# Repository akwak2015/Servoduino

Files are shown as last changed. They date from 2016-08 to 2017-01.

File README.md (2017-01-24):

# Servoduino
Mit einem Wemos Microcontroller und einem Servo Wandtablets mit Magnetsensor an und ausschalten. 

Zuerst einmal Danke an alle, die ihre Informationen zur Arduino Programmierung mit anderen teilen. ICh nutze in diesem Projekt Bibliotheken, die über den Manager downloadbar sind. 
Für die meisten Codeteile habe ich mich im Internet inspirieren lassen. Sollte sich jemand nicht ausreichend erwähnt finden, bitte direkt bescheid sagen, damit ich nachbessern kann.

####Was ist Servoduino?
Im Homematic Forum sind viele aktive User, die ein Tablett an die Wand hängen um ihre Hausautomation zu steuern. Dabei werden die verschiedensten Verfahren genutzt um as Tablett zur richtigen Zeit an- und auszschalten.
Desweitern hat jeder User seine eigene Ladestrategie um den Tablettakku zu Schonen.
Servoduino soll viele dieser Möglichkeiten zusammenfassen und kombinieren und das mit einem überschaubaren Hardwareaufwand.

####Ist Servoduino einsatzfähig
Teilweise ist es schon einsatzfähig.
#####Was läuft:
	-	Servo an/aus per Taster, Schalter und HTTP/UDP
	-	Relais an/aus per HTTP/UDP
	-	Rückmeldung an die Homematic CCU
	-	Rückmeldung an Loxone
	-	Option Schalter wie Taster (mit eigenem Timer)
	-	Option Taster mit eigenem Timer
	-	Analoger Eingang

#####Was läuft nicht:

####Welche Hausautomationssysteme werden unterstützt?
Aktuell werden unterstützt:
	-	Homematic
	-	Loxone
	
####Welche Protokolle werden zur Steuerung genutzt?
	-	HTTP
	- 	UDP
	
####Was wird benötigt?
Auf jeden Fall einen Wemos D1 Mini. (http://www.wemos.cc/Products/d1_mini.html)
Optional:
	-	Servo mit Magnet 
	-	Relay oder Relayshield (http://www.wemos.cc/Products/relay_shield_v2.html)
	-	Max. 2 Taster
	-	Max. 2 Schalter
	-	Analoger Ausgang bis 3V (z.B. Bewegungsmelder)

#####Wo wird die Hardware angeschlossen?
Die Pin angaben sind für den Wemos D1 Mini 
#####Pinbelegung:
| Hardware | Pin |
| --- | --- |
| Servo Motor | D4 |
| Taster | D5 und/oder D6 |
| Schalter | D7 			 |
| Relais | D1 |
| Analog Eingang | A0 |
 
####Welche Befehle werden verstanden?
#####HTTP:
| URL | Funktion |
| --- | --- |
| http://ip | Einfache Übersichts Seite |
| http://ip/setup | Konfiguration |
| http://ip/an | stellt den Servomotor in Position an  |
| http://ip/an?timer=Sekunden | stellt den Servomotor in Position an für die angegebene Zeitspanne  |
| http://ip/aus | stellt den Servomotor in Position aus |
| http://ip/ran | Relais an |
| http://ip/ran?timer=Sekunden  | Relais für Sekunden an |
| http://ip/raus | Relais aus |
| | |
| http://ip/status | Status des Servomotor |
| | |
| http://ip/resetwifi | WIFI Einstellungen zurücksetzen |
| http://ip/resetconfig | Einstellungen löschen |
| http://ip/werkseinstellungen  | Einstellungen und WIFI löschen |
| http://ip/restart | Wemos neu starten |

#####UDP:
| Befehl | Funktion |
| --- | --- |
| an | Servo auf an |
| aus | Servo auf aus |
| ran | Relais an |
| raus | Relais aus |
| status | liefert 1 oder 0 zurück für Position des Servo |
| rstatus | liefert 1 oder 0 zurück für Position des Relais |
 
######Warum sind die HTML Befehle so "komisch"
Viele von Euch würden jetzt warscheinlich Befehle im Format HTTP://IP/SERVO?POS=1 oder ähnlich erwarten. 
Grund dafür ist die Homematic Benutzeroberfläche. Da gibt es bei der Eingabe von Sonderzeichen für URLs leicht Probleme. Die o.a. Befehle lassen sich ohne Tricks eingeben.

#### Wie binde ich die Homematic ein?
Dafür wird uf der CCU das Addon CUxD benötigt (http://homematic-forum.de/forum/viewtopic.php?f=37&t=15298)
Ein Gerät (28) System als Schalter anlegen.  
  
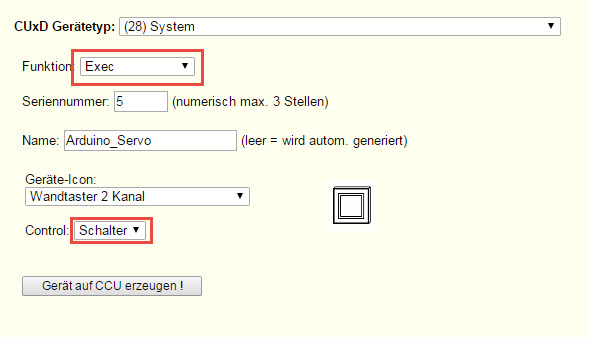
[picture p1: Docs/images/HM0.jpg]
  
  
Mit 2 Kanälen für Servo und Relais.  
In Param1: /usr/local/addons/cuxd/curl -s -m 5  
in Param2: http://ip.des.wemos.eintragen  
  
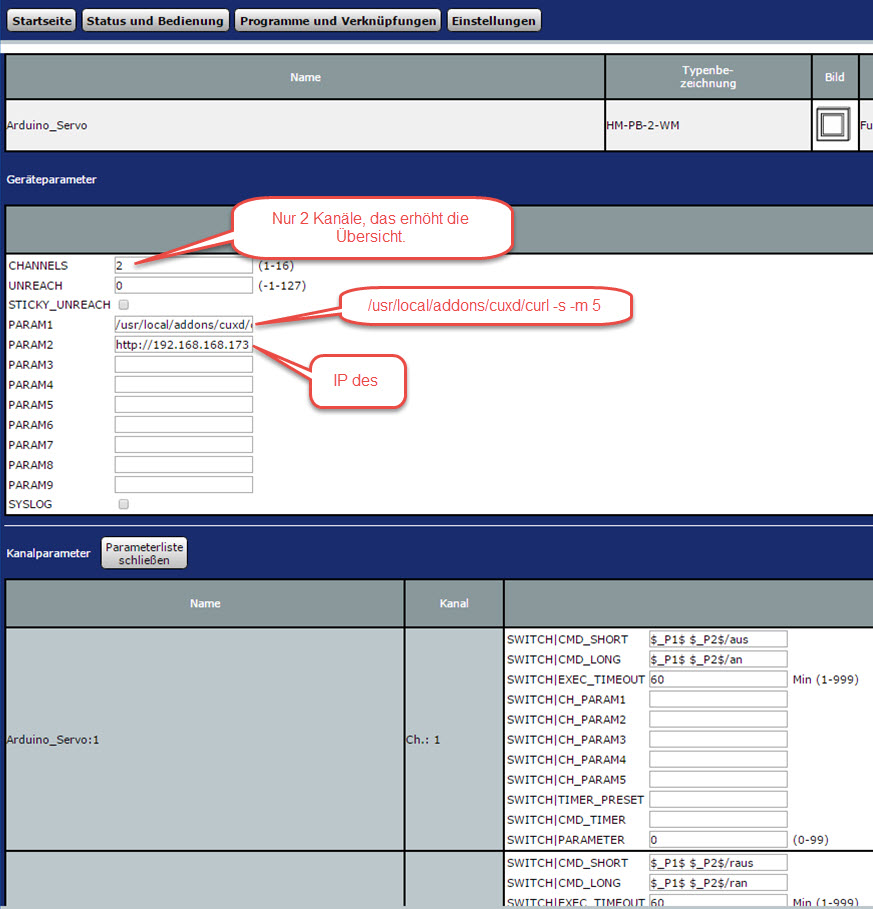
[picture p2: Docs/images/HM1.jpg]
  
  
Die Seriennummern beider Kanäle notieren  
  
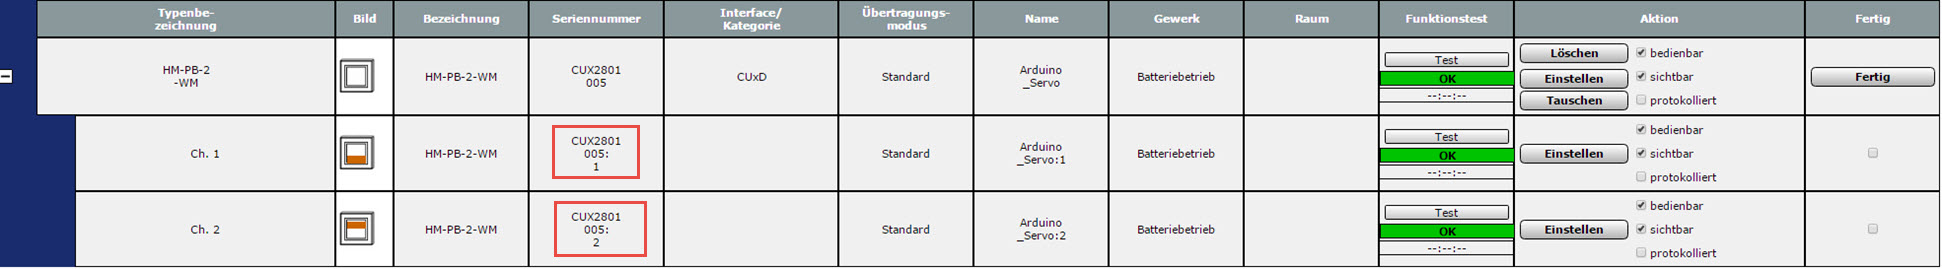
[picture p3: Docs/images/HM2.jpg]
  
  
Die IP der Homematic und die Seriennummern der beiden Kanäle im Setup auf dem Wemos eintragen
  
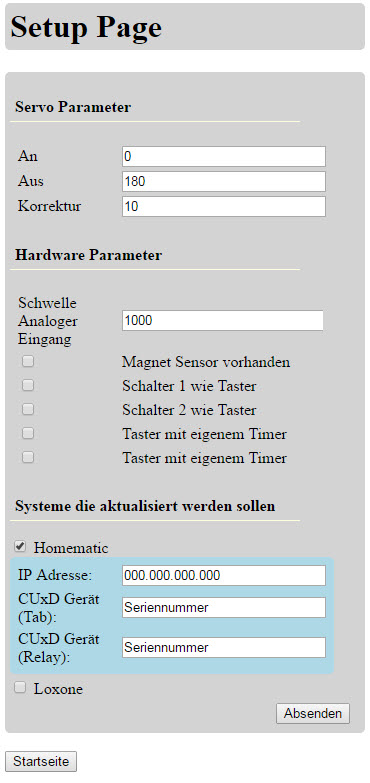
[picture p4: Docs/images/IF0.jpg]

  
####Wie binde ich Loxone ein?
Die Anwendung sendet an die angegebene IP Adresse auf dem angegebenen Port folgende Status:  
Für Jede Statusänderung des Servos oder Relais (0 für aus, 1 für an):  
	TAB1|0  
	RELAY1|0   
Für jede Taste/Schalter in eckigen Klammern [0 = Schalter 1, 1 = Schalter 2] gefolgt von 0 für aus, 1 für an:  
	Schalter[0]0|1  
	Taster[0|1]0|1  
	Web0|1  
	RWeb0|1

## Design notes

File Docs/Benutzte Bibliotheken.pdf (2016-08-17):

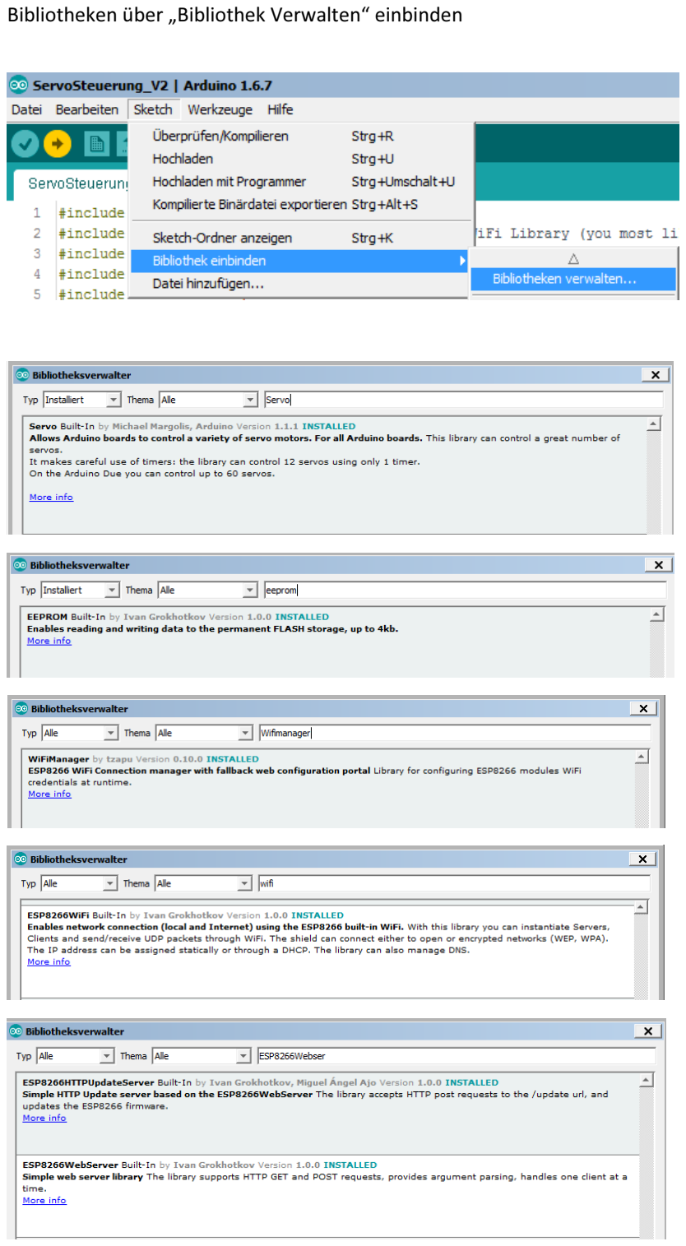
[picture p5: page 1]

Bibliotheken über „Bibliothek Verwalten“ einbinden

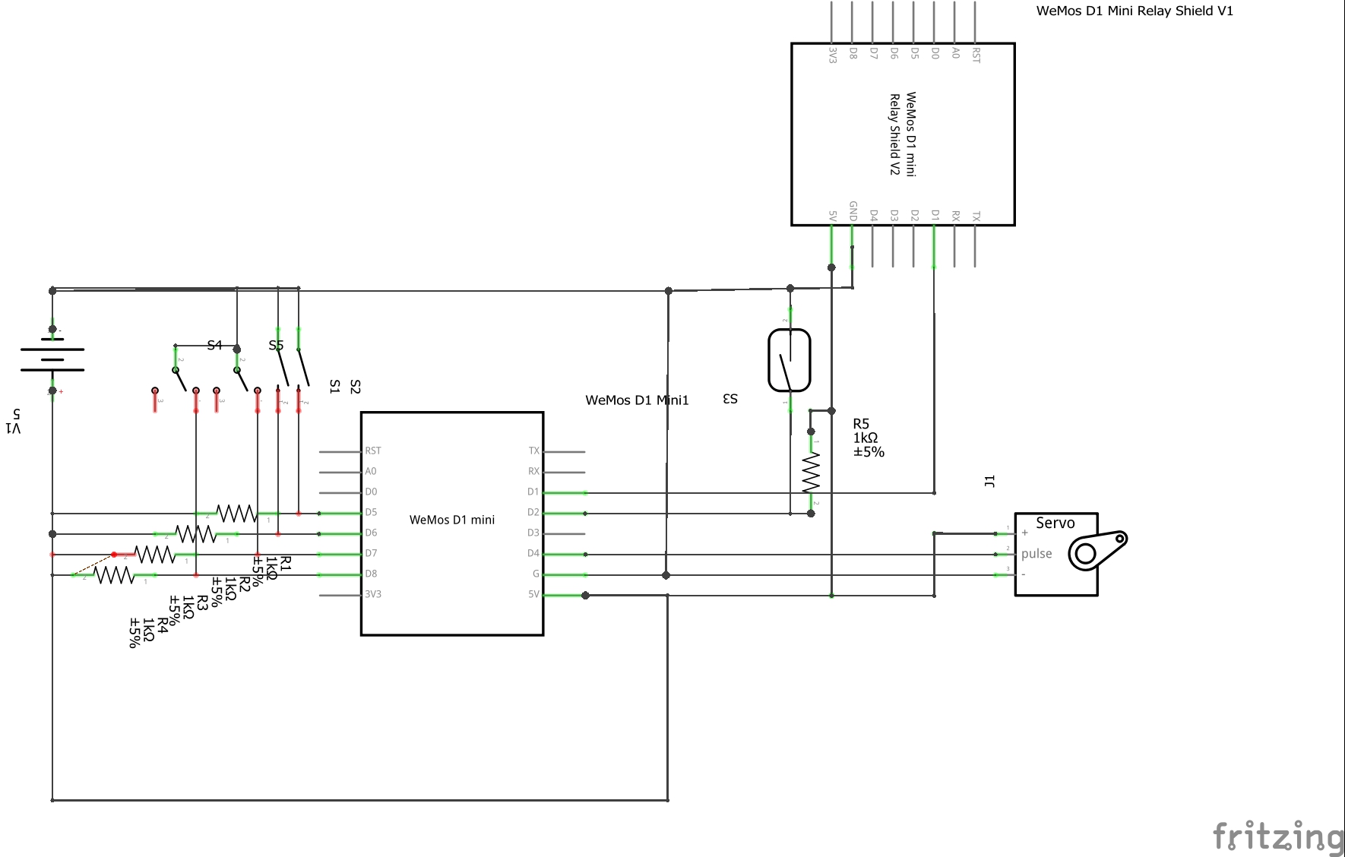
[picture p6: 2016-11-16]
Docs/Servo_Schaltplan.jpg

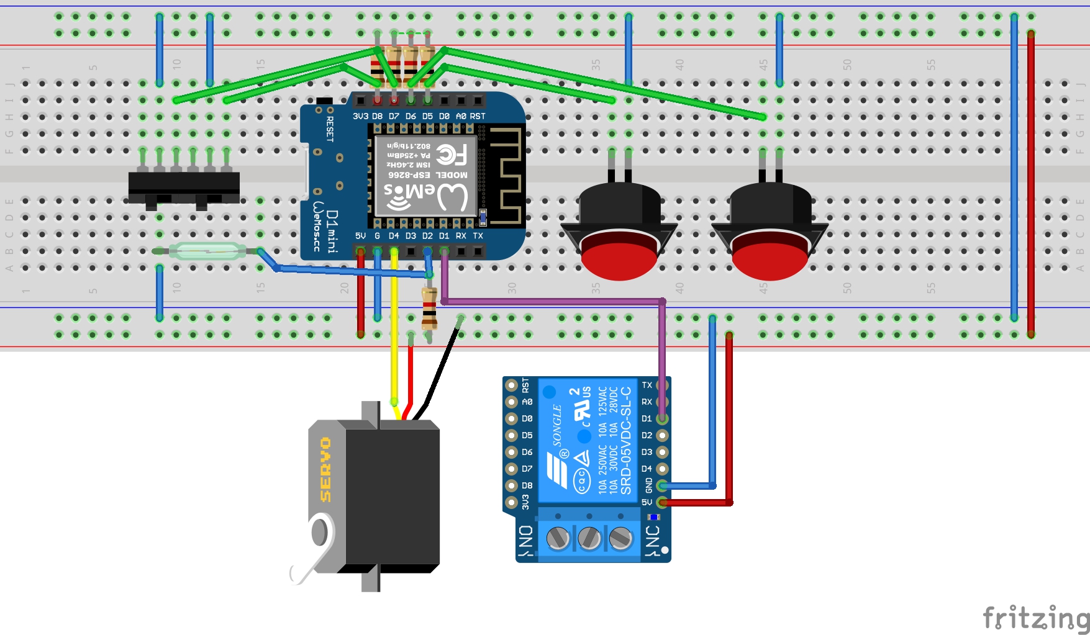
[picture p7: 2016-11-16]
Docs/Servo_Steckplatine.jpg

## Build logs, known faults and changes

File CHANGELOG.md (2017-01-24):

#Changelog:
a - added  
c - changed  
f - fixed  

##Version 0.9
c - Eingang für Reed Relais wird nicht mehr abgefragt
c - Der zweite Schaltereingang ist weggefallen
f - Analoger Input entprellt

##Version 0.8
c - Webui grafisch aufgehübscht  

##Version 0.7 
a - Timer für Relais hinzugefügt  
c - Aufgeteilt auf mehrere Dateien

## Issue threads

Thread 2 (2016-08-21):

Fehlerhafte Rückmeldung bei Schaltern

akwak2015, 2016-08-21:
Bei den Schaltern kommt immer der Gleiche Befehl im Loxone UDP Monitor an. Taster[1] und danach nichts mehr.

akwak2015, 2016-08-22:
Konvertierung String nach Char greift in einigen Fällen zu kurz. Dabei wird das letzte Zeichen verschluckt.
Workaround: Beim Konvertieren mehr Zeichen angeben als notwendig. Nicht schön, geht aber.

Closed 2016-08-26.

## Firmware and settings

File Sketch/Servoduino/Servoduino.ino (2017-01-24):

#include <ESP8266WiFi.h>          //ESP8266 Core WiFi Library (you most likely already have this in your sketch)
#include <DNSServer.h>            //Local DNS Server used for redirecting all requests to the configuration portal
#include <ESP8266WebServer.h>
#include <ESP8266HTTPClient.h> 
#include <ESP8266HTTPUpdateServer.h>
#include <WiFiManager.h>
#include <Servo.h>
#include <WiFiUdp.h>
#include <EEPROM.h>

#define iSwitchPinCount 1
#define iPushButtonPinCount 2

struct oconfig {
  int bValidConfig1;
  int bValidConfig2;
  int iConfigVersion;
  int iAn;
  int iAus;
  int iKorrektur;
  int bSwitchAsPushButton[iSwitchPinCount];
  int iSwitchTimer[iSwitchPinCount];
  int bPushButtonTimer[iPushButtonPinCount];
  int iPushButtonTimer[iPushButtonPinCount];
  int bMagnetsensor;
  int iAnalogSchwelle;
  int bHomematic;
  char sHomematicIP[16];
  char sHomematicGeraet[20];
  char sHomematicGeraetRelay[20];
  int bLoxone;
  char sLoxoneIP[16];
  char sLoxonePort[20];  
  int bIP;
  char sIP[16];
  char sSubNet[16];
  char sGateway[16]; 
  int bExpLogic;  // Schaltlogic der eingänge (switch gegen +5V oder GND) (0 fuer gegen GND)
  int iAnalogTimer;
};
typedef struct oconfig oConfig;


// *******************************************************************
// ******* Globale Variablen *****************************************
// *******************************************************************

//Version
//$Revision: 21 $
String sVersionDatum = "2017-01-20";
String sVersion = "0.9";

oConfig myConfig = {1234, 4321, 4, 0, 180, 10, {0}, {60}, {0, 0}, {120, 120}, 0 , 1000, 0, "000.000.000.000", "Seriennummer","Seriennummer", 0, "000.000.000.000", "7000" , 0, "000.000.000.000", "000.000.000.000", "000.000.000.000", 0, 120};

//Pin Definitionen
int iServoPin = 2; //WeMos mini D4
int iPushButtonPin[] = {14, 12}  ; //WeMos mini D5 und D6 (Groesse des Arrays in iPushButtonPinCount definiert (weiter oben))
int iSwitchPin[] = {13}; //WeMos mini D7 (Groesse des Arrays in iSwitchPinCount definiert (weiter oben))
int iRelayPin = 5; //Wemos mini D1 -> RelayBoard
int iMagnetsensorPin = 4; //Wemos mini D2 - MagnetSensor (Wird aktuell nicht mehr benutzt!)
// Analog Pin auf Wemos A0 => int sensorValue = analogRead(A0); 

// Aktueller Servo Status
int iServoPosAkt = -1;
int iTimerOffTime = 0;
// OTA
const char* update_path = "/firmware";
const char* update_username = "admin";
const char* update_password = "admin";

int iUeber = 0; //notwendiger "negatiever" Korrekturfaktor fue den Bereich ueber 180-iKorrektur.

int iPushButtonLastState[] = { 0, 0 };
unsigned long tPushButtonLast[2]; //letzter Tastendruck
int iSwitchLastState[] = { 0, 0 };
unsigned long tSwitchLast[2]; //letzte Schalterbetätigung

int iAnalogLastState = 0;
int iAnaloglastMillis = millis();

unsigned long iTimerMillis = millis();
bool bTimerAktiv = false;
unsigned long iRelayTimerMillis = millis();
bool bRelayTimerAktiv = false;

unsigned int localPort = 2390;      // local port to listen on
char packetBuffer[255]; //buffer to hold incoming packet
char  ReplyBuffer[] = "acknowledged";       // a string to send back

// *******************************************************************
// ******* Libraries         *****************************************
// *******************************************************************
WiFiManager wifiManager;
ESP8266WebServer server(80); // Webserver initialisieren auf Port 80
Servo myservo;
ESP8266HTTPUpdateServer httpUpdater;
WiFiUDP Udp;


// *******************************************************************
// ****** Prototypes  ************************************************
// *******************************************************************
//mycss
String cssForm();
String cssSwitch();
//myforms
void htmlresponse(String sTitel, String sInhalt);
String htmlFunction();
String htmlSwitch(String sName, int bStatus);
void wwwSetup();
void wwwRoot();
void wwwmelde_status();
void wwwmelde_FullStatus();
void htmlreloadpresite(String sTarget, String sText);
void htmlresponse0(String sText);
void wwwSwitchLogic();
//myhandler
void handlePushButton(int iPB);
void handleSwitch(int iSW);
void handleudp();
void handleAnalog();
void handleTimer();
void handleRelayTimer();
//Main
int getServo (bool bForcePinRead = false);
int getOnOffStatus(bool bForcePinRead = false);
int getStatus(bool bForcePinRead = false);
bool logichandler(int iPin = 0);

// *******************************************************************
// ******* Programm          *****************************************
// *******************************************************************

void setServo(int iPos) {
  myservo.attach(iServoPin); 
  delay(20);
  myservo.write(iPos);
  iServoPosAkt = iPos;
  delay(500);
  myservo.detach(); 
}

int getServo (bool bForcePinRead) {
  int iErg=0;
  if (bForcePinRead) {Serial.println("Force " + bForcePinRead);}
  if ((iServoPosAkt == -1) or (bForcePinRead)) {
    myservo.attach(iServoPin); 
    delay(500);
    iErg = myservo.read();
    delay(500);
    myservo.detach(); 
  }
  else {
    iErg=iServoPosAkt;
  }
  return iErg;
}

// Timer in Sekunden
void setTimerSec(int iTime) { 
  iTimerMillis = millis()+(1000 * iTime);
  bTimerAktiv = true;
  Serial.println(String(millis()) + "Timer aktiv: " + String(1000*iTime));
}

void setRelayTimerSec(int iTime) { 
  iRelayTimerMillis = millis()+(1000 * iTime);
  bRelayTimerAktiv = true;
  Serial.println("Relay Timer aktiv: " + String(1000*iTime));
}

void saveConfig() {
  Serial.println("__________ Save Config ________");
  int eeAddress = 0;
  EEPROM.begin(256);
  EEPROM.put(eeAddress, myConfig);
  delay(200);
  EEPROM.end();
}


int getKorrigiert (int iGrad) {
  int iErg = iGrad;
  iErg = iErg + myConfig.iKorrektur;
  iUeber=0;
  if (iErg > 180) { 
    iUeber=iErg-180;
    if (iUeber>myConfig.iKorrektur) iUeber=myConfig.iKorrektur;
    iErg=180;
  }
  if (iErg < 0) iErg=0;
  // Serial.println("getKorrigiert - Input: " + String(iGrad) + " Rueckgabe: "+ String(iErg));
  return iErg;
}

int getStatus(bool bForcePinRead) {
  int iErg = getServo(bForcePinRead);
  iErg=iErg - myConfig.iKorrektur;
  if (iErg > 180) iErg=180;
  if (iErg < 0) iErg=0;
  //Serial.println("getKorrigiert - ServoPos: " + String( getServo()) + " Rueckgabe: "+ String(iErg));
  return iErg+iUeber;
}

int getOnOffStatus(bool bForcePinRead) {
    int iErg=-1;
//    if (myConfig.bMagnetsensor==1) {
//      delay(500);
//      if (logichandler(iMagnetsensorPin) == HIGH) {
//        iErg=1;
//      } else {
//        iErg=0;
//      }
//  } else {    
    int iStatus = getStatus(bForcePinRead);
    if (iStatus == myConfig.iAn) iErg=1; 
    if (iStatus == myConfig.iAus) iErg=0; 
//  }
  return iErg;
}

// Rückmeldungen an Loxone

void sendUDP(String sUDP) {
    if (myConfig.bLoxone != 1) {return;}
    int iPort =  atoi(myConfig.sLoxonePort); 
    Serial.print("Anzahl Zeichen:");
    Serial.println(sizeof(sUDP)+2); //+2 um sicher alle Zeichen zu erwischen.
    char  sBuffer[sizeof(sUDP)] = "";
    sUDP.toCharArray(sBuffer,sizeof(sUDP)+2);
    Serial.print("Sende an Loxone: ");
    Serial.println(sBuffer); 
    Udp.beginPacket(myConfig.sLoxoneIP, iPort);
    Udp.write(sBuffer);
    Udp.endPacket(); 
}
void sendTabState2Loxone() {
//    if (myConfig.bLoxone != 1) {return;}
//    int iPort =  atoi(myConfig.sLoxonePort); 
//    int iStatus = getOnOffStatus();
//    char  sBuffer[6] = "";
//    String("TAB" + String(iStatus)).toCharArray(sBuffer,6);
//    Serial.print("Sende an Loxone: ");
//    Serial.println(sBuffer); 
//    Udp.beginPacket(myConfig.sLoxoneIP, iPort);
//    Udp.write(sBuffer);
//    Udp.endPacket();
    if (myConfig.bLoxone != 1) {return;}
    int iStatus = getOnOffStatus();
    sendUDP("TAB" + String(iStatus));
}
void sendRelayState2Loxone() {
    if (myConfig.bLoxone != 1) {return;}
//    int iPort  = atoi(myConfig.sLoxonePort); 
//    int iStatus = (iRelayPin);
//    char  sBuffer[8] = "";
//    String("RELAY" + String(iStatus)).toCharArray(sBuffer,8); 
//    Serial.print("Sende an Loxone: ");
//    Serial.println(sBuffer); 
//    Udp.beginPacket(myConfig.sLoxoneIP, iPort);
//    Udp.write(sBuffer);
//    Udp.endPacket();
    int iStatus = digitalRead(iRelayPin);
    sendUDP("Relay" + String(iStatus));
}

// Rückmeldungen an Homematic
void sendHTML(String sURL) {
  HTTPClient http;
  Serial.print("[HTTP] begin...\n");
  Serial.println(sURL);
  http.begin(sURL);
  int httpCode = http.GET();
  if(httpCode > 0) {
      // HTTP header has been send and Server response header has been handled
      Serial.printf("[HTTP] GET... code: %d\n", httpCode);

      // file found at server
      if(httpCode == HTTP_CODE_OK) {
          String payload = http.getString();
          Serial.println(payload);
      }
  } else {
      Serial.printf("[HTTP] GET... failed, error: %s\n", http.errorToString(httpCode).c_str());
  }

  http.end();

}

void sendTabState2HM(){
  if (myConfig.bHomematic != 1) {return;}
  String sURL ="http://";
  sURL += myConfig.sHomematicIP;
  sURL += ":8181/cuxd.exe?x=dom.GetObject(\"CUxD.";
  sURL += myConfig.sHomematicGeraet;
  sURL +=".SET_STATE\").State(";
  sURL += String(getOnOffStatus());
  sURL += ")";
  sendHTML(sURL);  
}

void sendRelayState2HM(){
  if (myConfig.bHomematic != 1) {return;}
  String sURL ="http://";
  sURL += myConfig.sHomematicIP;
  sURL += ":8181/cuxd.exe?x=dom.GetObject(\"CUxD.";
  sURL += myConfig.sHomematicGeraetRelay;
  sURL +=".SET_STATE\").State(";
  sURL +=  digitalRead(iRelayPin);
  sURL += ")";
  sendHTML(sURL);  
}

void sendTabState() {
  sendTabState2Loxone();
  sendTabState2HM();  
}

void sendRelayState() {
  sendRelayState2Loxone();
  sendRelayState2HM();
}

void sendState() {
  sendTabState();
  sendRelayState();
}


void goPos() {
  if (server.arg("pos")!="") {
//  String sStatus = server.arg("pos");
//  iStatus=sStatus.toInt();    
  int iStatus = server.arg("pos").toInt();
  if (iStatus<0) { iStatus = 0; }
  if (iStatus>360) { iStatus = 360; }
   
  setServo(getKorrigiert(iStatus));
  htmlresponse0(String(getStatus()));
  }
}

void wwwrelayan() {
  String bReload = server.arg("reload");
  String sTimer = server.arg("timer");
  int iTimer=0;
  digitalWrite(iRelayPin, HIGH);
  if (sTimer!="") {
    iTimer = sTimer.toInt();
      if (iTimer > 0) {
          setRelayTimerSec(iTimer);   
      }
  }
  else {
     bRelayTimerAktiv = false;
  } 

  if (bReload == "1") {
    Serial.println("Zur Root Seite weiterleiten");
    htmlreloadpresite("/","AN");
  }
  else {
    Serial.println("NICHT weiterleiten");
    htmlresponse0("1");
  }
    sendUDP("RWeb1");
    sendRelayState();  
}

void wwwrelayaus() {
  String bReload = server.arg("reload");
  digitalWrite(iRelayPin, LOW);
  bRelayTimerAktiv = false;
  if (bReload == "1") {
    Serial.println("Zur Root Seite weiterleiten");
    htmlreloadpresite("/","AUS");
  }
  else {
    Serial.println("NICHT weiterleiten");
    htmlresponse0("0");
  }
  sendUDP("RWeb0");
  sendRelayState(); 
}

void wwwan() {
  String bReload = server.arg("reload");
  String sTimer = server.arg("timer");
  int iTimer=0;
  Serial.println("Reload? = " + bReload);
  Serial.println("Timer? = " + sTimer);
  int iStatus=myConfig.iAn;
  setServo(getKorrigiert(iStatus));
  if (sTimer!="") {
    iTimer = sTimer.toInt();
      if (iTimer > 0) {
          setTimerSec(iTimer);   
      } 
  }
  else {
      bTimerAktiv = false;
  }

  if (bReload == "1") {
    Serial.println("Zur Root Seite weiterleiten");
    htmlreloadpresite("/","AN");
  }
  else {
    Serial.println("NICHT weiterleiten");
    htmlresponse0("1");
  }
  sendUDP("Web1");
  sendTabState();  
}

void wwwaus() {
  String bReload = server.arg("reload");
  Serial.println("Reload? = " + bReload);
  int iStatus=myConfig.iAus;
  setServo(getKorrigiert(iStatus));
  if (bReload == "1") {
    Serial.println("Zur Root Seite weiterleiten");
    htmlreloadpresite("/","AUS");
  }
  else {
    Serial.println("NICHT weiterleiten");
    htmlresponse0("0");
  }
  sendUDP("Web0");
  sendTabState();
  bTimerAktiv=false;  
}

void  wwwanwert() {
    int sensorValue = analogRead(A0);
    htmlresponse0(String(sensorValue));  
}



String htmlDisplay(int iState) {
  String sRet = "";
  if (iState == 1) {
     sRet = "style=\"display: inline-block;\"";
  }
  else {
     sRet = "style=\"display: none;\"";
  }
  return sRet;
}


void wwwSave() {
  String sAn = server.arg("an");
  String sAus = server.arg("aus");
  String sKorrektur = server.arg("korrektur");
  String sSchalterWieTaster1 = server.arg("SchalterWieTaster1");
  String sSchalterTime1 = server.arg("SchalterTime1");
  String sTasterMitTimer1 = server.arg("TasterMitTimer1");
  String sTasterTime1 = server.arg("TasterTime1");
//  String sSchalterWieTaster2 = server.arg("SchalterWieTaster2");
//  String sSchalterTime2 = server.arg("SchalterTime2");
  String sTasterMitTimer2 = server.arg("TasterMitTimer2");
  String sTasterTime2 = server.arg("TasterTime2");
  String sMagnetSchalter = server.arg("MagnetSchalter");
  String sAnalogSchwelle = server.arg("AnalogSchwelle");
    
  String sHM = server.arg("HM");
//  -----
  String sHMIP = server.arg("HMIP");
  String sHMGERAET = server.arg("HMGERAET");
  String sHMGERAETRELAY = server.arg("HMGERAETRELAY");
//  -----  
  String sLox = server.arg("Lox");
  String sLoxIP = server.arg("LoxIP");
  String sLoxPort = server.arg("LoxPort");
// IP ---
  String bIP = server.arg("FesteIP");
  String sIP = server.arg("IP");
  String sSubNet = server.arg("Sub");
  String sGateway = server.arg("GW"); 
  String bExpLogic = server.arg("Logic");
  String sAnalogTimer = server.arg("AnalogTime");

  Serial.println("Save Parameter Temporarly ------");
  Serial.println("an:                 " + sAn );
  Serial.println("aus:                " + sAus );
  Serial.println("korrektur:          " + sKorrektur );
  Serial.println("-------------------------------");
  Serial.println("SchalterWieTaster1: " + sSchalterWieTaster1 );
  Serial.println("SchalterTime1:      " + sSchalterTime1 );
  Serial.println("TasterMitTimer1:    " + sTasterMitTimer1 );
  Serial.println("TasterTime1:        " + sTasterTime1 );
  Serial.println("---");
//  Serial.println("SchalterWieTaster2: " + sSchalterWieTaster2 );
//  Serial.println("SchalterTime2:      " + sSchalterTime2 );
  Serial.println("TasterMitTimer2:    " + sTasterMitTimer2 );
  Serial.println("TasterTime2:        " + sTasterTime2 );
  Serial.println("Analog Time:        " + sAnalogTimer);
//  Serial.println("MagnetSchater:      " + sMagnetSchalter );
  Serial.println("AnalogSchwelle:     " + sAnalogSchwelle );

  Serial.println("-------------------------------");
  Serial.println("Homematic           " + sHM );
  Serial.println("Homematic IP        " + sHMIP );
  Serial.println("Homematic Geraet    " + sHMGERAET );
  Serial.println("Homematic Geraet Re " + sHMGERAETRELAY );
  Serial.println("Loxone              " + sLox );
  Serial.println("Loxone IP           " + sLoxIP );
  Serial.println("Loxone Geraet       " + sLoxPort );
  Serial.println("-------------------------------");
  Serial.println("Feste IP:           " + bIP);
  Serial.println("IP                  " + sIP);
  Serial.println("Subnet              " + sSubNet);
  Serial.println("Gateway             " + sGateway); 
  Serial.println("-------------------------------");
  Serial.println("Logic               " + String(bExpLogic));
  Serial.println("-------------------------------");
 
  if (sAn!="") {myConfig.iAn = sAn.toInt();}
  if (sAus!="") {myConfig.iAus = sAus.toInt();}
  if (sKorrektur!="") {myConfig.iKorrektur = sKorrektur.toInt();}

// -------------------- Schalter wie Taster   --------------
// Schalter 1
  if (sSchalterWieTaster1 =="on") {
      myConfig.bSwitchAsPushButton[0] = 1;
      if (sSchalterTime1!="") {
         myConfig.iSwitchTimer[0] = sSchalterTime1.toInt();
      }
  }
  else {
    myConfig.bSwitchAsPushButton[0] = 0;
  }

//Schalter 2
//  if (sSchalterWieTaster2 =="on") {
//      myConfig.bSwitchAsPushButton[1] = 1;
//      if (sSchalterTime2!="") {
//         myConfig.iSwitchTimer[1] = sSchalterTime2.toInt();
//      }
//  }
//  else {
//    myConfig.bSwitchAsPushButton[1] = 0;
//  }

// ---------------------- Taster mit Timer -------------------
//Taster 1  
  if (sTasterMitTimer1 =="on") {
       myConfig.bPushButtonTimer[0] = 1;
      if (sTasterTime1!="") {
         myConfig.iPushButtonTimer[0] = sTasterTime1.toInt();
      }
  }
  else {
     myConfig.bPushButtonTimer[0] = 0;
  }
  
// Taster 2
  if (sTasterMitTimer2 =="on") {
       myConfig.bPushButtonTimer[1] = 1;
      if (sTasterTime2!="") {
         myConfig.iPushButtonTimer[1] = sTasterTime2.toInt();
      }
  }
  else {
     myConfig.bPushButtonTimer[1] = 0;
  }

// Analog Timer
  if (sAnalogTimer!="") {
     myConfig.iAnalogTimer = sAnalogTimer.toInt();
  }

  //Quick and dirty - Magnetsensorfunktion deaktivieren
  myConfig.bMagnetsensor = 0;
//  if (sMagnetSchalter =="on") {
//          myConfig.bMagnetsensor = 1;
//      } else {
//          myConfig.bMagnetsensor = 0;
//      }

  if (sAnalogSchwelle !="") { myConfig.iAnalogSchwelle = sAnalogSchwelle.toInt();}
  
// ----- Homematic
  if (sHM =="on") { 
        myConfig.bHomematic = 1;
     } else {
        myConfig.bHomematic = 0;        
     }
   
  if (sHMIP !="") { sHMIP.toCharArray(myConfig.sHomematicIP,16);}
  if (sHMGERAET !="") { sHMGERAET.toCharArray(myConfig.sHomematicGeraet ,20);}
  if (sHMGERAETRELAY !="") { sHMGERAETRELAY.toCharArray(myConfig.sHomematicGeraetRelay ,20);}

// -----Loxone
  if (sLox =="on") { 
        myConfig.bLoxone = 1;
     } else {
        myConfig.bLoxone = 0;
     }

  if (sLoxIP !="") { sLoxIP.toCharArray(myConfig.sLoxoneIP,16) ;}
  if (sLoxPort  !="") { sLoxPort.toCharArray( myConfig.sLoxonePort ,20);}

  if (bIP =="on") { 
        myConfig.bIP = 1;
     } else {
        myConfig.bIP = 0;        
     }
   
  if (sIP != "") { sIP.toCharArray(myConfig.sIP,16);}
  if (sSubNet != "") { sSubNet.toCharArray(myConfig.sSubNet ,16);}
  if (sGateway != "") { sGateway.toCharArray(myConfig.sGateway,16);} 

  if (bExpLogic =="on") {
    myConfig.bExpLogic = 1;
    }
    else {
      myConfig.bExpLogic = 0;
    }
  saveConfig();
  delay(200);
  htmlreloadpresite("/setup","Speicher Parameter");
 
}


void printConfig() {
 Serial.println("Valid1 (1234): " + String(myConfig.bValidConfig1));
 Serial.println("Valid2 (4321): " + String(myConfig.bValidConfig2));  
 Serial.println("Config Ver.  : " + String(myConfig.iConfigVersion));
 Serial.println("An           : " + String(myConfig.iAn));
 Serial.println("Aus          : " + String(myConfig.iAus));
 Serial.println("Korrektur    : " + String(myConfig.iKorrektur));
 Serial.println("SwitchAsPush : " + String(myConfig.bSwitchAsPushButton[0]));
 Serial.println("SwitchTimer  : " + String(myConfig.iSwitchTimer[0]));
 Serial.println("PB with Timer: " + String(myConfig.bPushButtonTimer[0]));
 Serial.println("PB Timer     : " + String(myConfig.iPushButtonTimer[0]));  
// Serial.println("SwitchAsPush : " + String(myConfig.bSwitchAsPushButton[1]));
// Serial.println("SwitchTimer  : " + String(myConfig.iSwitchTimer[1]));
 Serial.println("PB with Timer: " + String(myConfig.bPushButtonTimer[1]));
 Serial.println("PB Timer     : " + String(myConfig.iPushButtonTimer[1]));
 Serial.println("Analog Timer : " + String(myConfig.iAnalogTimer)); 
 Serial.println("Homematic    : " + String(myConfig.bHomematic)); 
 Serial.println("Homatic IP   : " + String(myConfig.sHomematicIP)); 
 Serial.println("Homematic Ger: " + String(myConfig.sHomematicGeraet)); 
 Serial.println("Loxone       : " + String(myConfig.bLoxone)); 
 Serial.println("Loxone IP    : " + String(myConfig.sLoxoneIP)); 
 Serial.println("Loxone Geraet: " + String(myConfig.sLoxonePort)); 
 Serial.println("Logic Inputs : " + String(myConfig.bExpLogic)); 

}
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
void loop() {
  // put your main code here, to run repeatedly:
    server.handleClient(); // auf HTTP-Anfragen warten
    for (int i=0; i<iPushButtonPinCount ; i++) {
        handlePushButton(i);
    }    
    for (int i=0; i<iSwitchPinCount ; i++) {
        handleSwitch(i);
    }
    handleAnalog();
    handleudp();
    handleTimer();
    handleRelayTimer();
    delay(100);
}

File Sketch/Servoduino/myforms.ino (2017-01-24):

String htmlSwitch(String sName, int bStatus, String sID ="") {
  String sReturn;
  String sStatus = "";
  if (bStatus==1) {
    sStatus="checked";
  }
  sReturn = "<label class=\"switch\">";
  sReturn += "<input type=\"checkbox\" name=\""+sName+"\" "+ sStatus ;
  if (sID !="") {sReturn += " onchange = \"showhide('"+sID + "' , this.checked)\"";}
  sReturn += ">";
  sReturn += "<div class=\"slider round\"></div>";
  sReturn += "</label>";
  return(sReturn);
}

String htmlFunction() {
  String sReturn ="\n";
  sReturn += "<script type=\"text/javascript\">\n";
  sReturn += "function toggle(control){\n";
  sReturn += "    var elem = document.getElementById(control);\n";
  sReturn += "\n";
  sReturn += "    if(elem.style.display == \"none\"){\n";
  sReturn += "        elem.style.display = \"inline-block\";\n";
  sReturn += "    }else{\n";
  sReturn += "        elem.style.display = \"none\";\n";
  sReturn += "    }\n";
  sReturn += "}\n";

  sReturn += "function showhide(control, val){\n";
  sReturn += "  var elem = document.getElementById(control);\n";
  sReturn += "  if(val){\n";
  sReturn += "    elem.style.display = \"inline-block\"\n";
  sReturn += "  }else{\n";
  sReturn += "    elem.style.display = \"none\";\n";
  sReturn += "  }\n";
  sReturn += "}\n";  
  sReturn += "</script>\n";

  sReturn += "<script type=\"text/javascript\">\n";
  sReturn += "var xmlHttpObject = false;\n";
  sReturn += "// Überprüfen ob XMLHttpRequest-Klasse vorhanden und erzeugen von Objekte für IE7, Firefox, etc.\n";
  sReturn += "if (typeof XMLHttpRequest != 'undefined') \n";
  sReturn += "{\n";
  sReturn += "    xmlHttpObject = new XMLHttpRequest();\n";
  sReturn += "}\n";
  sReturn += "";
  sReturn += "// Wenn im oberen Block noch kein Objekt erzeugt, dann versuche XMLHTTP-Objekt zu erzeugen\n";
  sReturn += "// Notwendig für IE6 oder IE5\n";
  sReturn += "if (!xmlHttpObject) \n";
  sReturn += "{\n";
  sReturn += "    try \n";
  sReturn += "    {\n";
  sReturn += "        xmlHttpObject = new ActiveXObject(\"Msxml2.XMLHTTP\");\n";
  sReturn += "    }\n";
  sReturn += "    catch(e) \n";
  sReturn += "    {\n";
  sReturn += "        try \n";
  sReturn += "        {\n";
  sReturn += "            xmlHttpObject = new ActiveXObject(\"Microsoft.XMLHTTP\");\n";
  sReturn += "        }\n";
  sReturn += "        catch(e) \n";
  sReturn += "        {\n";
  sReturn += "            xmlHttpObject = null;\n";
  sReturn += "        }\n";
  sReturn += "    }\n";
  sReturn += "}</script>\n";

  sReturn += "<script type=\"text/javascript\">\n";
  sReturn += "function sndReq()\n";
  sReturn += "{\n";   
  sReturn += "xmlHttpObject.open('get', '/anwert', true);\n";
  sReturn += "xmlHttpObject.send();";
  sReturn += "  xmlHttpObject.onreadystatechange = function () {\n";
  sReturn += "    if(xmlHttpObject.readyState == 4)\n";
  sReturn += "    {\n";
  sReturn += "      document.getElementById('divAnWert').innerHTML = xmlHttpObject.responseText\n";
  sReturn += "    }\n";
  sReturn += "  }\n";
  sReturn += "  http.send(null);\n";
  sReturn += "}\n";
  sReturn += "</script>  \n";

  sReturn += "<script type=\"text/javascript\">\n";
  sReturn += "function sndReqFull()\n";
  sReturn += "{\n";   
  sReturn += "xmlHttpObject.open('get', '/fullstatus', true);\n";
  sReturn += "xmlHttpObject.send();\n";
  sReturn += "  xmlHttpObject.onreadystatechange = function () {\n";
  sReturn += "    if(xmlHttpObject.readyState == 4)\n";
  sReturn += "    {\n";
  sReturn += "      document.getElementById('divFull').innerHTML = xmlHttpObject.responseText\n";
  sReturn += "    }\n";
  sReturn += "  }\n";
//  sReturn += "  http.send(null);\n";
  sReturn += "}\n";
  sReturn += "</script>  \n";
  return sReturn;
}
void htmlresponse(String sTitel, String sInhalt) {
    String sResponse;
    Serial.println("htmlresponse begin");
    sResponse  = "<!DOCTYPE HTML PUBLIC \"-//W3C//DTD HTML 4.01//EN\" \"http://www.w3.org/TR/html4/strict.dtd\">\n";
    sResponse += "<html lang=\"de\"><head>\n";
    sResponse += "<meta http-equiv=\"content-type\" content=\"text/html; charset=utf-8\">\n";
    sResponse += "<Style type=\"text/css\">\n";
    sResponse += cssSwitch();
    sResponse += cssForm();
    sResponse += "</style>\n";
    sResponse += htmlFunction();
    sResponse += "<title>\n";
    sResponse += sTitel;
    sResponse += "</title></head><body>\n";
    sResponse += sInhalt;
    sResponse += "</body></html>\n";
    Serial.println("htmlresponse write to client");
    server.send(200, "text/html", sResponse);
    Serial.println("htmlresponse end");
}


void wwwSetup() {
  Serial.println("wwwrSetup begin");
  String sResp="";
  sResp += "<h1>Setup Page</h1>\n";
  sResp += "<div class=\"all\">\n";
  sResp += "<form action=\"/save\" id=\"Servoduino\"  method=\"post\" autocomplete=\"off\">\n";
  sResp += "  <p class=\"sys2inf\"><b>Servo Parameter</b></p>\n";
  sResp += "  <table class=\"fixed\">\n";
  sResp += "    <TR>\n";
  sResp += "      <TD class=\"first\">\n";
  sResp += "        An\n";
  sResp += "      </TD>\n";
  sResp += "      <TD class=\"second\">\n";
  sResp += "        <input class=\"field\" name=\"an\" type=\"number\" min=\"0\" max=\"180\" step=\"5\" value=\""+ String(myConfig.iAn) + "\">\n";
  sResp += "      </TD>\n";
  sResp += "    </TR>\n";
  sResp += "    <TR>\n";
  sResp += "      <TD class=\"first\">\n";
  sResp += "        Aus\n";
  sResp += "      </TD>\n";
  sResp += "      <TD class=\"second\">\n";
  sResp += "        <input class=\"field\" name=\"aus\" type=\"number\" min=\"0\" max=\"180\" step=\"5\" value=\""+ String(myConfig.iAus) + "\">\n";
  sResp += "      </TD>\n";
  sResp += "    </TR>\n";
  sResp += "    <TR>\n";
  sResp += "      <TD class=\"first\">\n";
  sResp += "        Korrektur\n";
  sResp += "      </TD>\n";
  sResp += "      <TD class=\"second\">\n";
  sResp += "        <input class=\"field\" name=\"korrektur\" type=\"number\" min=\"-90\" max=\"90\" step=\"5\" value=\""+ String(myConfig.iKorrektur) + "\">\n";
  sResp += "      </TD>\n";
  sResp += "    </TR>\n";
  sResp += "  </Table>\n";
  sResp += "\n";
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

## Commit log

2016-08-22 ISSUE #1 - War schon teilweise implementiert ISSUE #2 - Rückmeldung korrigiert für Schalter
    [Servoduino.ino]
2016-08-26 Fix: UDP Rückmeldung jetzt vollständig Change: Rückmeldung sowohl für Tastendrücke / Webaktivitäten als auch für Servo aktivität new: Timer funktionalität
    [Servoduino.ino]
2016-08-29 Timer für Relais hinzugefügt Struktur überarbeitet und auf mehrere Dateien aufgeteilt.
2016-09-05 Servo wird nach setzen der Position abgemeldet (detach) damit wird Issue #3 (flatternder Servo) adressiert.
    [Servoduino.ino, myforms.ino, myhandler.ino]
2016-10-26 In Absprache mit dem Hersteller der Tablett Rahmen ist Taster und Schalter Logic umgebaut auf Schalten/Tasten über GND.
    [Servo.fzz]
2016-11-16 Fehler beim Reed Kontakt behoben.
    [Servo.fzz]
2017-01-17 Anpassungen und Reduktionen
2017-01-24 Magnetsensor wird nicht mehr unterstützt Schaltereingang 2 deaktiviert, da er auf dem Wemos Probleme bereitet hat Analoger eingang funktioniert jetzt relativ zuverlässig
    [Servoduino.ino, myforms.ino, myhandler.ino]
